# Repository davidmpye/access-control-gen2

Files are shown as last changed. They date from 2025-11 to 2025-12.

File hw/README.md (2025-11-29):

# Hardware 

Contains two 3D printable parts:

* Mounting bracket - PLA, 30% infil.  Requires 8 M3 brass threaded inserts, four to mount PCB to bracket, and 4 to mount the bracket to the inside of a box.

* RFID pillar - need to print two of these, and requires 4 M3 threaded inserts. Used to affix RFID reader securely to PCB.

For the housing, we used IP55 Junction Boxes (double) from [ToolStation](https://www.toolstation.com/ip55-junction-box/p60297)

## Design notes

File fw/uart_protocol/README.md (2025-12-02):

# uart_protocol

## Purpose

This crate defines the messaging protocol used between the main access control unit and a remote card reader unit (UART over RS485).
RS485 is used to try to avoid problems previously encountered with the MFRC522 misbehaving and refusing to read cards (likely due to misusing SPI bus over a number of metres!)

### RemoteMessage (from remote to main unit):

These are as follows:

* SingleUid([u8;4]),

Read an NFC card with a 4 byte UID

* DoubleUid([u8;7]),

Read an NFC card with a 7 byte UID

* TripleUid([u8;10]),

Read an NFC card with a 10 byte UID

* ReadError,     

Failed to read a card

* ReaderFault,

Reader fault (eg not present)

* JustReset,

Sends on powerup (or if the rp2040 is reset by the watchdog - usually because the reader isn't present/faulty!)

* KeepAlive,

Routine keepalive message - nothing to see here

### MainMessage (from main unit to remote)

* AccessGranted,  

Put green LED on (if fitted) to indicate successful device/door activation

* AccessDenied,  

Put red LED on (if fitted) to indicate unsuccessful device/door activation

* AwaitingCard,  

Quiescent state (usually, both LEDs off)

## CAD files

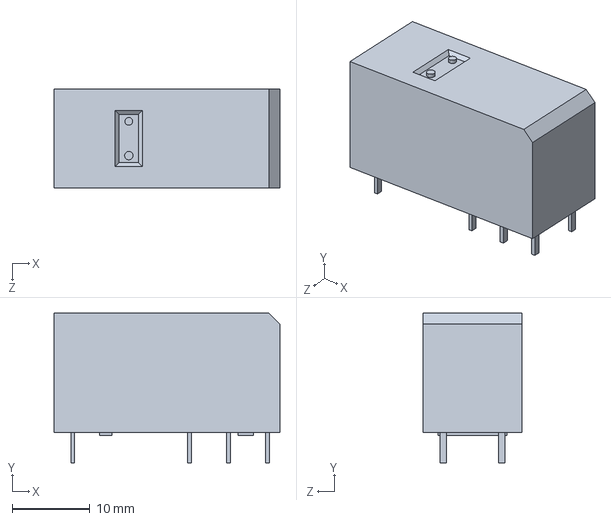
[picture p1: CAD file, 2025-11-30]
pcb/mains_controller/G2RL_1_E.step
29.0 x 19.2 x 12.7 mm

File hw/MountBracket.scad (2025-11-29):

hole_dir_outer=8.5;
hole_dir_inner=4;
$fn=100;

height=17;

difference () {
union () {
    
translate([-5,-5,0]) cube([60,70,5]);
translate([0, 0,0]) pillar(hole_dir_outer,hole_dir_inner,height);
translate([50, 0,0]) pillar(hole_dir_outer,hole_dir_inner,height);
translate([0, 60,0]) pillar(hole_dir_outer,hole_dir_inner,height);
translate([50, 60,0]) pillar(hole_dir_outer,hole_dir_inner,height);
}

translate([0, 0,-0.01]) cylinder(d=4, h=8);
translate([50, 0,-0.01]) cylinder(d=4, h=8);
translate([0, 60,-0.01]) cylinder(d=4, h=8);
translate([50, 60,-0.01]) cylinder(d=4, h=8);
}

module pillar(outer, inner, height) {
    difference() {
        cylinder(d=outer, h=height);
        translate([0,0,height/2 + 0.1]) cylinder(d=inner, h=height/2);
    }
}

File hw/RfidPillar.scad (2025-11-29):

hole_dir_outer=7;
hole_dir_inner=4;
//Takes M3 threaded brass inserts
$fn=100;

height=12;
pillar(hole_dir_outer,hole_dir_inner,height);

module pillar(outer, inner, height) {
    difference() {
        cylinder(d=outer, h=height);
        translate([0,0,-0.1]) cylinder(d=inner, h=height + 0.2);
    }
}

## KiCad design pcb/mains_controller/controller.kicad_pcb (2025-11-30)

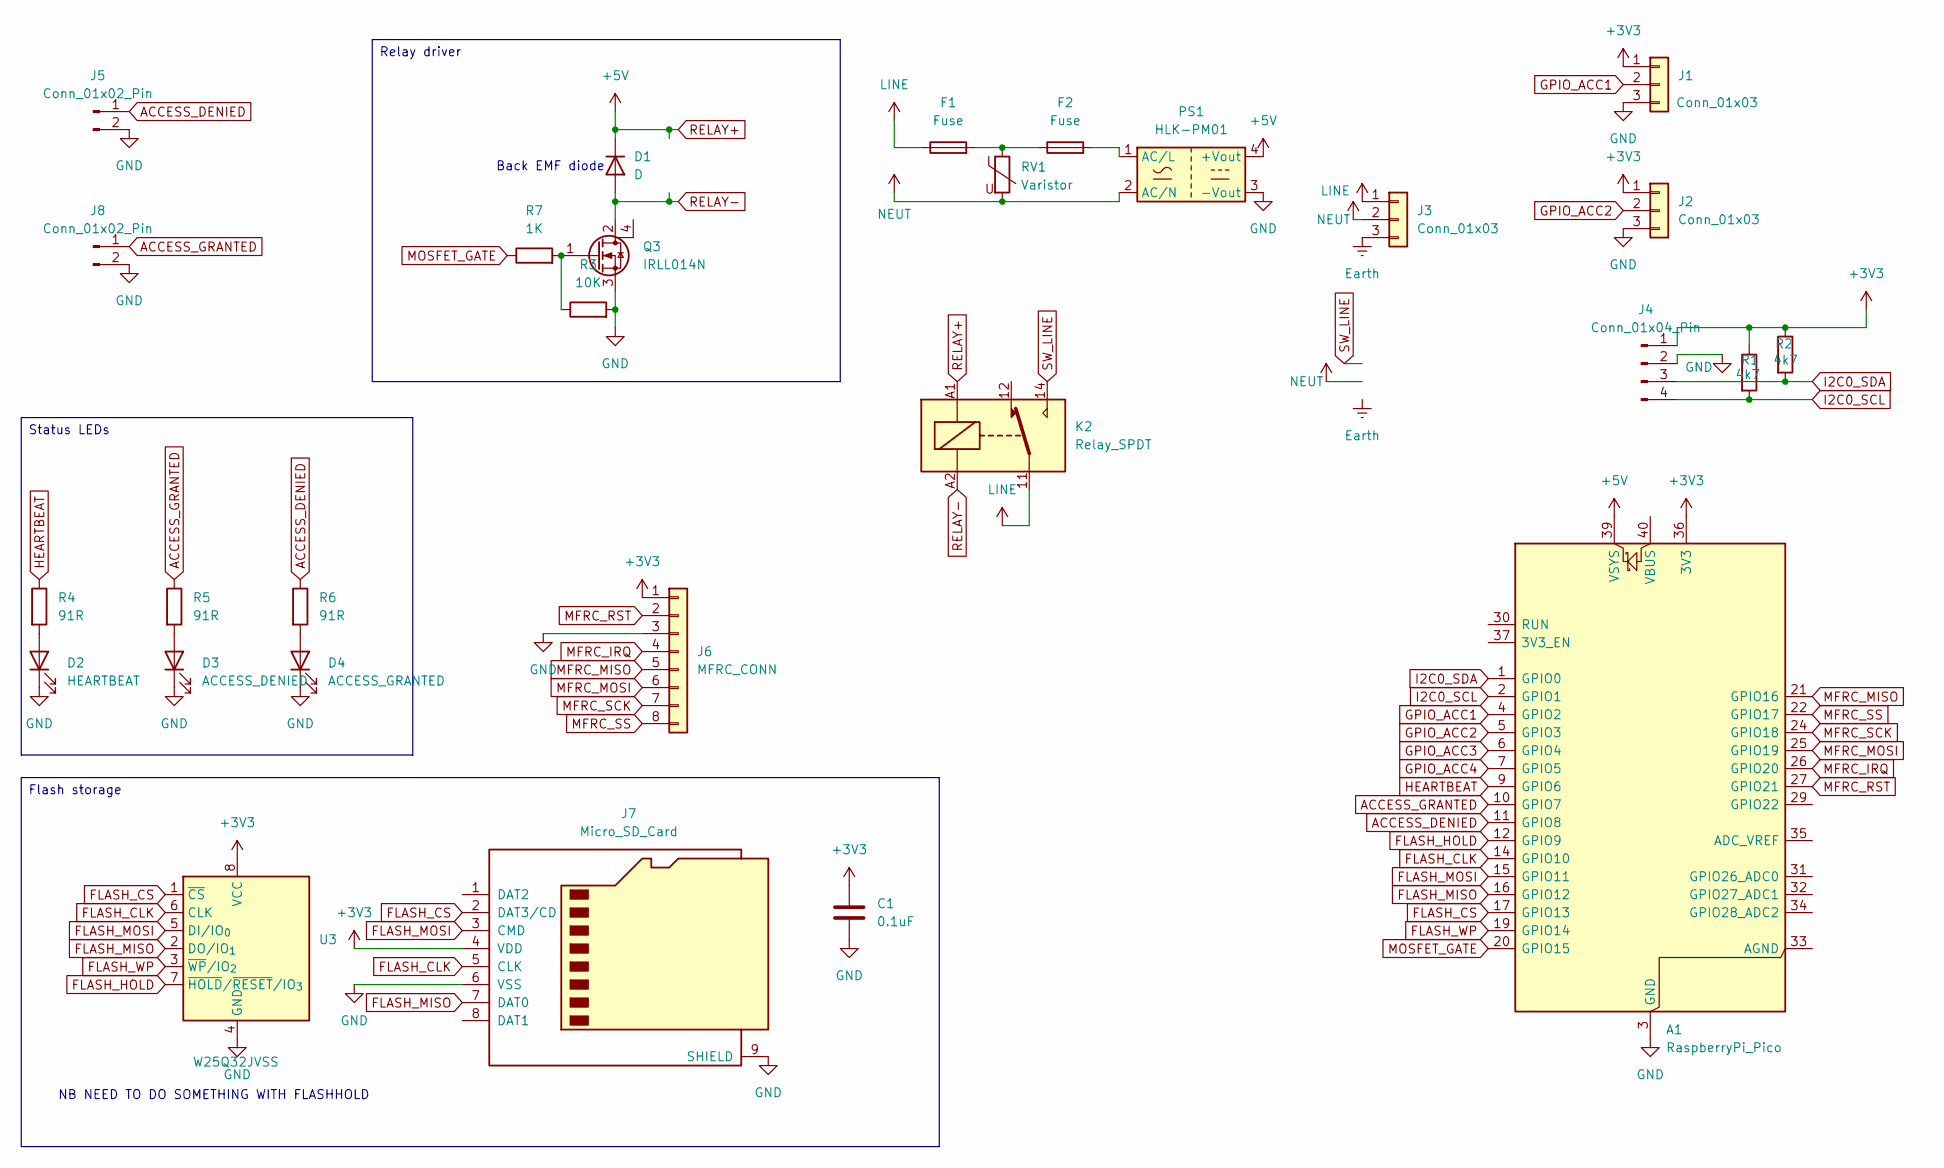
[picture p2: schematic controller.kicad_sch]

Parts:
A1: RaspberryPi_Pico; RaspberryPi_Pico_SMD_HandSolder
C1: 0.1uF; C_1206_3216Metric_Pad1.33x1.80mm_HandSolder
D1: D; D_SMA-SMB_Universal_Handsoldering
D2: HEARTBEAT; LED_1206_3216Metric_Pad1.42x1.75mm_HandSolder
D3: ACCESS_DENIED; LED_1206_3216Metric_Pad1.42x1.75mm_HandSolder
D4: ACCESS_GRANTED; LED_1206_3216Metric_Pad1.42x1.75mm_HandSolder
F1: Fuse; Fuseholder_Clip-5x20mm_Keystone_3517_Inline_P23.11x6.76mm_D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
F2: Fuse; R_Axial_DIN0204_L3.6mm_D1.6mm_P5.08mm_Horizontal
J1, J2: Conn_01x03; JST_XH_B3B-XH-A_1x03_P2.50mm_Vertical
J3: Conn_01x03; TerminalBlock_MetzConnect_Type073_RT02603HBLU_1x03_P5.08mm_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
J4: Conn_01x04_Pin; JST_XH_B4B-XH-A_1x04_P2.50mm_Vertical
J5, J8: Conn_01x02_Pin; JST_XH_B2B-XH-A_1x02_P2.50mm_Vertical
J6: MFRC_CONN; PinHeader_1x08_P2.54mm_Vertical
J7: Micro_SD_Card; microSD_HC_Molex_104031-0811
K2: Relay_SPDT; Relay_SPDT_Omron_G2RL-1-E
PS1: HLK-PM01; Converter_ACDC_Hi-Link_HLK-PMxx
Q3: IRLL014N; SOT-223-3_TabPin2
R1, R2: 4k7; R_1210_3225Metric_Pad1.30x2.65mm_HandSolder
R3: 10K; R_1210_3225Metric_Pad1.30x2.65mm_HandSolder
R4, R5, R6: 91R; R_1210_3225Metric_Pad1.30x2.65mm_HandSolder
R7: 1K; R_1210_3225Metric_Pad1.30x2.65mm_HandSolder
RV1: Varistor; RV_Disc_D7mm_W4.9mm_P5mm
U3: W25Q32JVSS; SOIC-8_5.3x5.3mm_P1.27mm

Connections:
+3V3: A1.36 (3V3), C1.1, J1.1, J2.1, J4.1, J6.1, J7.4 (VDD), R1.1, R2.1, U3.8 (VCC)
ACCESS_DENIED: A1.11 (GPIO8), J5.1, R6.1
ACCESS_GRANTED: A1.10 (GPIO7), J8.1, R5.1
Earth: J3.3; also elsewhere on the board
FLASH_CLK: A1.14 (GPIO10), J7.5 (CLK), U3.6 (CLK)
FLASH_CS: A1.17 (GPIO13), J7.2 (DAT3/CD), U3.1 (~CS)
FLASH_HOLD: A1.12 (GPIO9), U3.7 (~HOLD/~RESET/IO_{3})
FLASH_MISO: A1.16 (GPIO12), J7.7 (DAT0), U3.2 (DO/IO_{1})
FLASH_MOSI: A1.15 (GPIO11), J7.3 (CMD), U3.5 (DI/IO_{0})
FLASH_WP: A1.19 (GPIO14), U3.3 (~WP/IO_{2})
GND: A1.3 (GND), A1.8 (GND), A1.13 (GND), A1.18 (GND), A1.23 (GND), A1.28 (GND), A1.38 (GND), C1.2, D2.1 (K), D3.1 (K), D4.1 (K), J1.3, J2.3, J4.2, J5.2, J6.3, J7.6 (VSS), J7.9 (SHIELD), J8.2, PS1.3 (-Vout), Q3.3 (S), R3.2, U3.4 (GND)
GPIO_ACC1: A1.4 (GPIO2), J1.2
GPIO_ACC2: A1.5 (GPIO3), J2.2
GPIO_ACC3: A1.6 (GPIO4)
GPIO_ACC4: A1.7 (GPIO5)
HEARTBEAT: A1.9 (GPIO6), R4.1
I2C0_SCL: A1.2 (GPIO1), J4.4, R1.2
I2C0_SDA: A1.1 (GPIO0), J4.3, R2.2
LINE: F1.1, J3.1, K2.11
MFRC_IRQ: A1.26 (GPIO20), J6.4
MFRC_MISO: A1.21 (GPIO16), J6.5
MFRC_MOSI: A1.25 (GPIO19), J6.6
MFRC_RST: A1.27 (GPIO21), J6.2
MFRC_SCK: A1.24 (GPIO18), J6.7
MFRC_SS: A1.22 (GPIO17), J6.8
MOSFET_GATE: A1.20 (GPIO15), R7.1
NEUT: J3.2, PS1.2 (AC/N), RV1.2; also elsewhere on the board
unnamed: D2.2 (A), R4.2
unnamed: D3.2 (A), R5.2
unnamed: D4.2 (A), R6.2
unnamed: F1.2, F2.1, RV1.1
unnamed: F2.2, PS1.1 (AC/L)
unnamed: Q3.1 (G), R3.1, R7.2
RELAY+: A1.39 (VSYS), D1.1 (K), K2.A1, PS1.4 (+Vout)
RELAY-: D1.2 (A), K2.A2, Q3.2 (D)
SW_LINE: K2.14; also elsewhere on the board

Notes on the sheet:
NB NEED TO DO SOMETHING WITH FLASHHOLD
Back EMF diode
Status LEDs
Relay driver
Flash storage

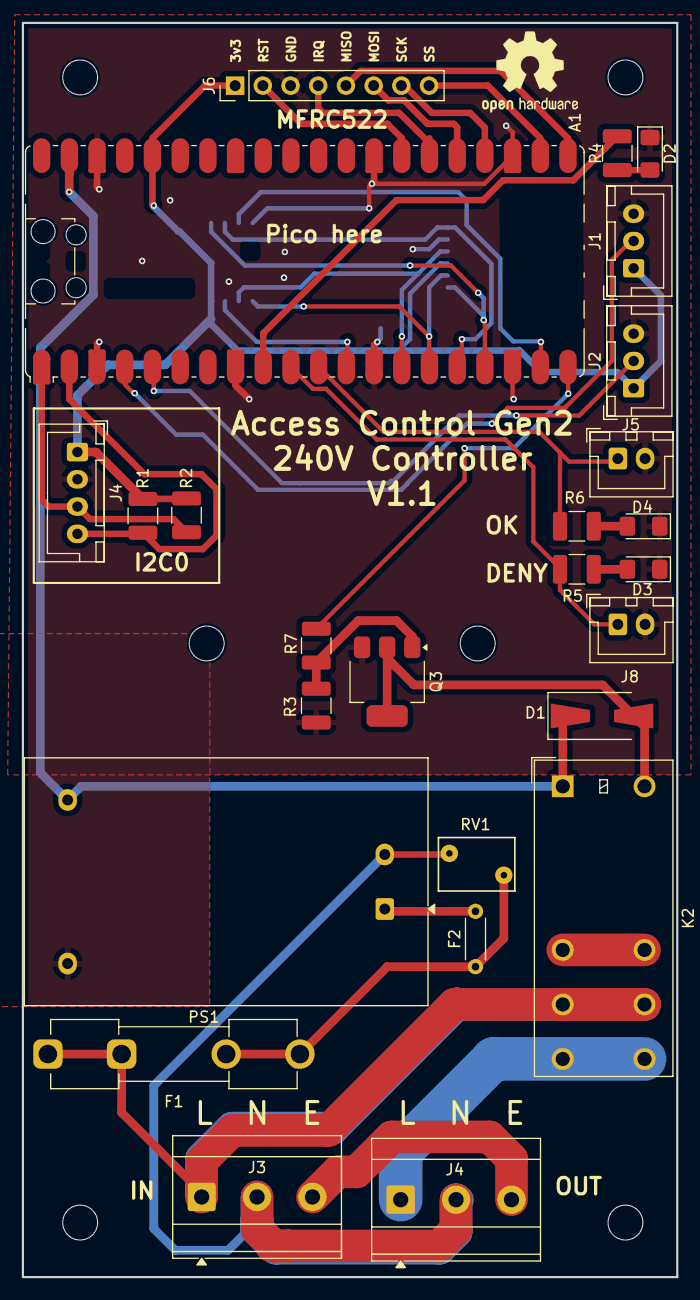
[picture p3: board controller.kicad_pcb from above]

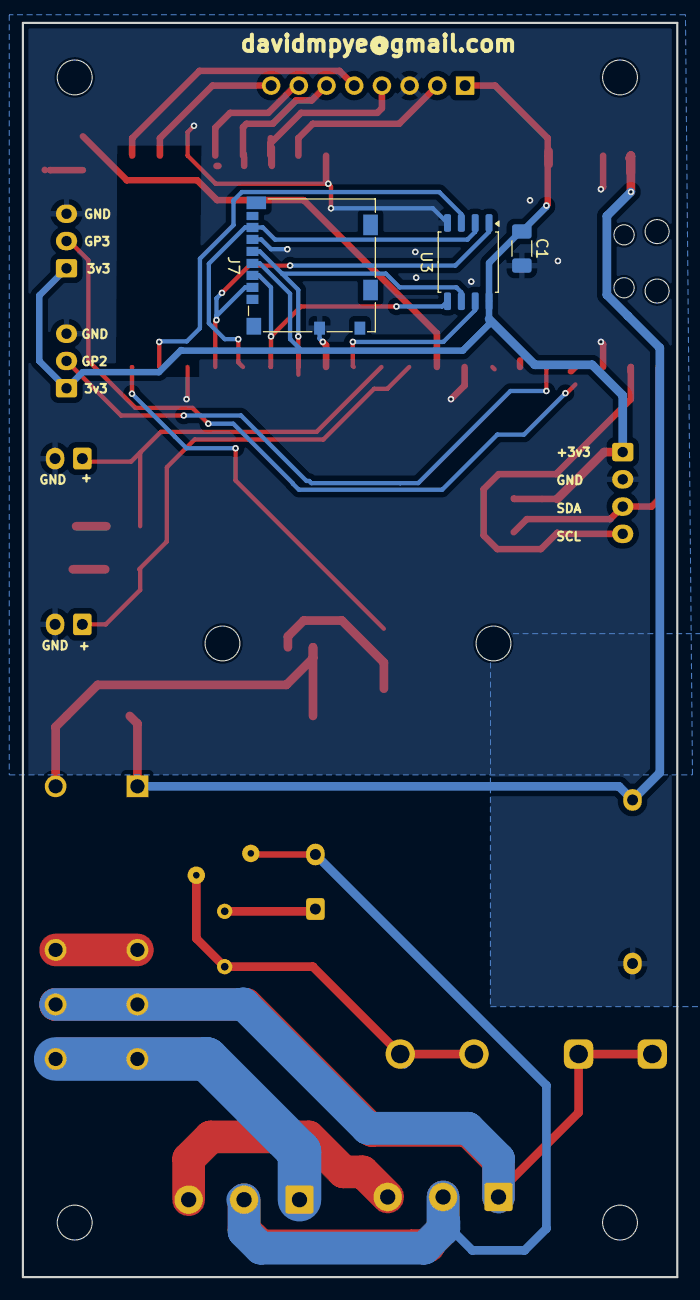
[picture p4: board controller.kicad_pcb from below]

Board: 2 copper layers, 60.0 x 115.0 mm, 29 parts (3 on the bottom side), 34 nets.

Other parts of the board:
J4#2: Conn_01x03; TerminalBlock_MetzConnect_Type073_RT02603HBLU_1x03_P5.08mm_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

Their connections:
Earth: J4#2.3; also elsewhere on the board
NEUT: J4#2.2; also elsewhere on the board
SW_LINE: J4#2.1; also elsewhere on the board

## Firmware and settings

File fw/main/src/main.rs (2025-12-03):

#![no_std]
#![no_main]
#![allow(async_fn_in_trait)]

use cyw43::JoinOptions;
use cyw43_pio::{PioSpi, DEFAULT_CLOCK_DIVIDER};

//For SPI flash
use w25q32jv::W25q32jv;

use defmt::*;

use {defmt_rtt as _, panic_probe as _};

use embassy_executor::Spawner;
use embassy_net::{Config as WifiConfig, StackResources};
use embassy_rp::bind_interrupts;
use embassy_rp::clocks::RoscRng;
use embassy_rp::gpio::{Level, Output};
use embassy_rp::peripherals::{DMA_CH0, PIO0, UART0};
use embassy_rp::pio::{InterruptHandler, Pio};
use embassy_rp::spi::{Config as SpiConfig, Spi};
use embassy_rp::uart::{Config as UartConfig, InterruptHandler as UartInterruptHandler, Uart};
use embassy_time::{Delay, Timer};

use embedded_hal_bus::spi::{ExclusiveDevice, NoDelay};

use static_cell::StaticCell;

use rand::RngCore;

mod database_task;
mod local_cardreader_task;
mod log_task;
mod main_task;
mod remote_cardreader_task;
mod watchdog;

use database_task::DatabaseRunner;
use local_cardreader_task::LocalCardreaderTaskRunner;
use main_task::main_task;
use remote_cardreader_task::remote_cardreader_task;
use watchdog::watchdog_task;

use log_task::{LogEvent, LogTaskRunner, LOG_EVENT_QUEUE};
mod config;
use config::CONFIG;

bind_interrupts!(struct Irqs {
    PIO0_IRQ_0 => InterruptHandler<PIO0>;
    UART0_IRQ => UartInterruptHandler<UART0>;
});

#[embassy_executor::task]
async fn cyw43_task(
    runner: cyw43::Runner<'static, Output<'static>, PioSpi<'static, PIO0, 0, DMA_CH0>>,
) -> ! {
    runner.run().await
}

#[embassy_executor::task]
async fn net_task(mut runner: embassy_net::Runner<'static, cyw43::NetDriver<'static>>) -> ! {
    runner.run().await
}

#[embassy_executor::task]
async fn database_task(
    runner: DatabaseRunner<
        W25q32jv<
            ExclusiveDevice<
                Spi<'static, embassy_rp::peripherals::SPI1, embassy_rp::spi::Blocking>,
                Output<'static>,
                NoDelay,
            >,
            Output<'static>,
            Output<'static>,
        >,
    >,
) -> ! {
    runner.run().await
}

#[embassy_executor::task]
async fn log_task(runner: LogTaskRunner) -> ! {
    runner.run().await
}

#[embassy_executor::task]
async fn local_cardreader_task(
    mut runner: LocalCardreaderTaskRunner<
        ExclusiveDevice<
            Spi<'static, embassy_rp::peripherals::SPI0, embassy_rp::spi::Blocking>,
            Output<'static>,
            Delay,
        >,
        Output<'static>,
    >,
) -> ! {
    runner.run().await
}

#[embassy_executor::main]
async fn main(spawner: Spawner) {
    let p = embassy_rp::init(Default::default());

    //Spawn the watchdog task
    spawner.must_spawn(watchdog_task(p.WATCHDOG, Output::new(p.PIN_6, Level::High)));

    let pwr = Output::new(p.PIN_23, Level::Low);
    let cs = Output::new(p.PIN_25, Level::High);
    let mut pio = Pio::new(p.PIO0, Irqs);
    let spi = PioSpi::new(
        &mut pio.common,
        pio.sm0,
        DEFAULT_CLOCK_DIVIDER,
        pio.irq0,
        cs,
        p.PIN_24,
        p.PIN_29,
        p.DMA_CH0,
    );

    //Set up SPI1 for the flash memory storage
    let (sck, mosi, miso, cs) = (p.PIN_10, p.PIN_11, p.PIN_12, &p.PIN_13);
    let spi1: Spi<'_, embassy_rp::peripherals::SPI1, embassy_rp::spi::Blocking> =
        Spi::new_blocking(p.SPI1, sck, mosi, miso, SpiConfig::default());
    let flash_wp = Output::new(p.PIN_14, Level::Low); //WP is ACTIVE LOW - start with flash WP set
    let flash_hold = Output::new(p.PIN_9, Level::High); //Flash hold is ACTIVE LOW - start with hold not enabled
    let flash_cs = Output::new(p.PIN_13, Level::High); //SPI flash CS pin
    let spi_device = embedded_hal_bus::spi::ExclusiveDevice::new_no_delay(spi1, flash_cs);
    let mut spi_flash =
        W25q32jv::new(spi_device, flash_hold, flash_wp).expect("Unable to initialise flash");
    info!(
        "SPI flash (W25Q32) initialised - device id {}",
        spi_flash.device_id().expect("Unable to read flash ID")
    );

    //Wifi hardware setup
    static STATE: StaticCell<cyw43::State> = StaticCell::new();
    let fw = include_bytes!("../cyw43-firmware/43439A0.bin");
    let clm = include_bytes!("../cyw43-firmware/43439A0_clm.bin");
    let state = STATE.init(cyw43::State::new());
    let (net_device, mut control, runner) = cyw43::new(state, pwr, spi, fw).await;
    unwrap!(spawner.spawn(cyw43_task(runner)));

    control.init(clm).await;
    control
        .set_power_management(cyw43::PowerManagementMode::PowerSave)
        .await;

    // Init network stack
    let config = WifiConfig::dhcpv4(Default::default());
    let mut rng = RoscRng;
    let seed = rng.next_u64();
    static RESOURCES: StaticCell<StackResources<5>> = StaticCell::new();
    let (stack, runner) = embassy_net::new(
        net_device,
        config,
        RESOURCES.init(StackResources::new()),
        seed,
    );
    //Spawn network task
    unwrap!(spawner.spawn(net_task(runner)));

    //Set up channel to receive card hash
    //Set up the appropriate task to read from the card reader - either local (direct SPI) or remote (via RS485 link)
    if cfg!(not(feature = "remote-cardreader")) {
        info!("Local cardreader mode selected");
        info!("NB - if no cardreader, this will hang and reboot repeatedly (by watchdog)");
        //Local task - will poll SPI cardreader over local bus
        let (sck, mosi, miso, cs) = (p.PIN_18, p.PIN_19, p.PIN_16, p.PIN_17);
        let spi0 = Spi::new_blocking(p.SPI0, sck, mosi, miso, SpiConfig::default());
        let spi0: ExclusiveDevice<
            Spi<'_, embassy_rp::peripherals::SPI0, embassy_rp::spi::Blocking>,
            Output,
            Delay,
        > = ExclusiveDevice::new(spi0, Output::new(cs, Level::High), Delay);
        debug!("Spawning local card reader task");
        spawner.must_spawn(local_cardreader_task(LocalCardreaderTaskRunner::new(
            spi0,
            Output::new(p.PIN_21, Level::High),
        )));
    } else {
        //Remote task
        info!("Remote cardreader mode selected");
        let (tx_pin, rx_pin, uart) = (p.PIN_0, p.PIN_1, p.UART0);
        let uart = Uart::new(
            uart,
            tx_pin,
            rx_pin,
            Irqs,
            p.DMA_CH2,
            p.DMA_CH3,
            UartConfig::default(),
        );
        debug!("Spawning remote card reader task");
        spawner.must_spawn(remote_cardreader_task(uart));
    }

    //Spawn the main task
    let allowed = Output::new(p.PIN_7, Level::Low);
    let denied = Output::new(p.PIN_8, Level::Low);
    let relay_pin = Output::new(p.PIN_15, Level::Low);
    spawner.must_spawn(main_task(relay_pin, allowed, denied));

    //Spawn the database task
    spawner.must_spawn(database_task(DatabaseRunner::new(
        spi_flash,
        2 * 1024 * 1024, //2mbit
        0x00,
        stack,
    )));

    //Spawn the logger task
    spawner.must_spawn(log_task(LogTaskRunner::new(stack)));

    loop {
        match control
            .join(CONFIG.ssid, JoinOptions::new(CONFIG.wifi_pw.as_bytes()))
            .await
        {
            Ok(_) => {
                info!("WiFi network {} joined, configuring stack", CONFIG.ssid);
                break;
            }
            Err(err) => {
                error!(
                    "Failed to join {}, status {}, retrying in 10s",
                    CONFIG.ssid, err.status
                );
                Timer::after_secs(10).await;
            }
        }
    }

    //Complete init of Wifi stack
    debug!("DHCP init");
    stack.wait_config_up().await;
    debug!("Config ready, awaiting link up");
    stack.wait_link_up().await;
    debug!("Link ready, awaiting config up");
    stack.wait_config_up().await;
    info!("Wifi ready");
    //Main function is now complete - the peripherals/tasks/stack are operational
}

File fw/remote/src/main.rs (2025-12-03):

#![no_std]
#![no_main]

const DELAY_BETWEEN_READS:Duration = Duration::from_millis(2000);

use defmt::*;
use {defmt_rtt as _, panic_probe as _};

use embassy_executor::Spawner;
use embassy_rp::{gpio, gpio::{Level, Input, Output}, spi::{Config as SpiConfig,Spi}};
use embassy_time::{Delay, Duration, Timer};
use embedded_hal_bus::spi::ExclusiveDevice;

use embassy_rp::peripherals::{UART0, WATCHDOG};
use embassy_rp::uart::{Uart, UartRx, Async, Config as UartConfig, InterruptHandler};
use embassy_rp::watchdog::Watchdog;

use embassy_rp::bind_interrupts;

use heapless::Vec;
use mfrc522::{comm::blocking::spi::SpiInterface, Mfrc522, Uid};
use postcard::{to_vec_cobs, from_bytes_cobs};

use uart_protocol::{RemoteMessage, MainMessage, MainMessage::*};

#[derive(Debug, Format)]
pub enum RemoteError {
    RxBufferOverflow, //Message exceeded rx buffer length
    UartError,        //Uart read error
    PostcardError,    //Unable to decode message using postcard - byte corruption?
}

bind_interrupts!(struct Irqs {
    UART0_IRQ => InterruptHandler<UART0>;
});

const WATCHDOG_TIMER_SECS:u64 = 2;
const WATCHDOG_FEED_TIMER_MS:u64 = 250;

#[embassy_executor::task]
pub async fn watchdog_task(watchdog: WATCHDOG, mut led: Output<'static>) -> ! {
    let mut dog = Watchdog::new(watchdog);
    dog.start(Duration::from_secs(WATCHDOG_TIMER_SECS));
    loop {        
        dog.feed();
        Timer::after(Duration::from_millis(WATCHDOG_FEED_TIMER_MS)).await;
        led.toggle();
    }
}

#[embassy_executor::task]
async fn led_task(mut uart_rx: UartRx<'static, UART0, Async>, mut red_led: Output<'static>, mut green_led: Output<'static>) -> ! {
    //This function 'owns' the two IOs as red/green LEDs.
    loop{
        match read_message(&mut uart_rx).await {
            Ok(message) => {
                match message {
                    AccessGranted => {
                        green_led.set_low();
                    },
                    AccessDenied => {
                        red_led.set_low();
                    },
                    AwaitingCard => {
                        green_led.set_high();
                        red_led.set_high();
                    },
                }
            },
            Err(e) => {
                error!("LED task encountered UART read error: {}", e);
            }
        }
    }
}


async fn read_message<'d>(uart: &mut UartRx<'d, UART0, Async>) -> Result<MainMessage,RemoteError> {
    let mut buf = [0x00u8; 16];

    for index in 0..buf.len() {
        if let Ok(_) = uart.read(&mut buf[index..index + 1]).await {
            if buf[index] == 0x00u8 {
                //Message complete, cobs ensures 0x00 will never be part of message, just end marker
                //Decode message using from_bytes_cobs from Postcard
                let res: Result<MainMessage, postcard::Error> = from_bytes_cobs(&mut buf[0..index]);
                match res {
                    Ok(message) => return Ok(message),
                    Err(_e) => return Err(RemoteError::PostcardError),
                }
            }
        } else {
            //Unclear of the circumstances when uart.read returns an Error
            error!("Uart Rx error");
            return Err(RemoteError::UartError);
        }
    }
    //If we are here, we have hit the end of the buffer
    error!("Rx buffer overflow");
    return Err(RemoteError::RxBufferOverflow);
}


#[embassy_executor::main]
async fn main(spawner: Spawner) -> ! {
    // Initialise Peripherals
    let p = embassy_rp::init(Default::default());

    //Spawn the watchdog task first
    let heartbeat_led = Output::new(p.PIN_7, Level::Low);
    spawner.must_spawn(watchdog_task(p.WATCHDOG, heartbeat_led));

    //Set up pins
    let mut card_read_led = Output::new(p.PIN_6, Level::Low);
    
    //Set up the UART we use to speak over RS485 to the controller
    let (tx_pin, rx_pin, uart) = (p.PIN_0, p.PIN_1, p.UART0);
    let uart = Uart::new(uart, tx_pin, rx_pin, Irqs, p.DMA_CH0, p.DMA_CH1, UartConfig::default());

    let (mut uart_tx, uart_rx) = uart.split();

    //Leds on, 1 sec flash at power up
    let mut green_led = Output::new(p.PIN_3, Level::Low);
    let mut red_led = Output::new(p.PIN_2, Level::Low);
    Timer::after_millis(500).await;
    green_led.set_high();
    Timer::after_millis(500).await;
    red_led.set_high();
    //Spawn the status LED task, which owns the two GPIO ACC pins and the Rx half of the UART
    spawner.must_spawn(led_task(uart_rx, red_led, green_led));
    
    //This could be better - the newer embassy-rp watchdog is able to tell us if the reset is watchdog-origi
    debug!("Sending JustReset to controller");
    let vec: Vec<u8,16> = to_vec_cobs(&RemoteMessage::JustReset).unwrap();
    let _ = uart_tx.write(&vec).await;

    //Init SPI0 for talking to the card reader
    debug!("Init SPI0 peripheral");
    let (sck, mosi, miso, cs) = ( p.PIN_18, p.PIN_19, p.PIN_16, p.PIN_17);
    let cs = Output::new(cs, Level::High); //CS into output

    let spi0 = Spi::new_blocking(p.SPI0, sck, mosi, miso, SpiConfig::default());
    let mut spi0 = ExclusiveDevice::new(spi0, cs, Delay);

    //Nice idea to use MFRC IRQ pin but not supported by driver library presently
    let _irq = Input::new(p.PIN_20, gpio::Pull::Up);
    let mut rst = Output::new(p.PIN_21, Level::High);

    let mut last_sent_ok_message_counter = 0x00u8;
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

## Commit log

2025-08-02 Initial import of the kicad project for the controller. Update some of the rust project libraries
    [controller.kicad_pcb, controller.kicad_sch]
2025-11-11 Footprint updates Major restructuring
    [controller.kicad_pcb, controller.kicad_sch]
2025-11-13 Used 'format document' to adjust formatting. Shorten message queue length from 32->16 events
    [main.rs, main_task.rs, remote_cardreader.rs]
2025-11-27 PCB changes - add GPIO3/4
    [controller.kicad_pcb, controller.kicad_sch]
2025-11-27 Minor silkscreen changes
    [controller.kicad_pcb]
2025-11-27 Add mains controller branch
    [controller.kicad_pcb, controller.kicad_sch]
2025-11-29 Add printables
    [MountBracket.scad, RfidPillar.scad]
2025-11-29 Rename + add readme
    [MountBracket.scad, RfidPillar.scad]
2025-11-29 Start design for mains controller
    [controller.kicad_pcb, controller.kicad_sch]
2025-11-30 Production version (sent to JLC!)
    [G2RL_1_E.step, controller.kicad_pcb, controller.kicad_sch]
2025-12-01 Add digikey PNs
    [controller.kicad_sch]
2025-12-01 Restructure project directories and break out the uart_protocol into separate crate
2025-12-01 Complete migration to uart_protocol crate
2025-12-01 Add the uart_protocol bits
2025-12-01 Implementation of remote LED functionality
2025-12-02 Fix rust version to 2021 in uart protocol
2025-12-02 Add remote cardreader LED control messages
2025-12-02 Add signals for remote cardreader (fixme - only use signal if remote device present
    [main_task.rs]
2025-12-03 Change logic for LED (GPIO pull to low) Brief flash on power up
